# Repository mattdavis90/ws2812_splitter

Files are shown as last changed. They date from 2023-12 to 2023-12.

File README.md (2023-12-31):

# WS2812 Splitter

> [!WARNING]
> This project is still very much in beta and I am yet to receive the PCBs and fully verify the desgn.

A configurable splitter compatible with WS2812(B) LEDs. Splits the incoming signal two ways; the first is a copy of the input and the second is disabled for N LED's worth of data. This allows you to run two strips in parallel with each other.

The project is based on the work by [Pete on hackaday.io](https://hackaday.io/project/8181-ws2812b-delay-splitter). As far as I can tell Pete never got it working, this is intended to be a continuation of that work.

The project is being used personally for WS2812B Icicles. Rather than running wires from the bottom of each icicle back to the next LED (to create a continuous strip) this project allows you to place a 'tee' at the top of each icicle, that delays the continuing signal by the length of the drop.

This is maybe best viewed as an image

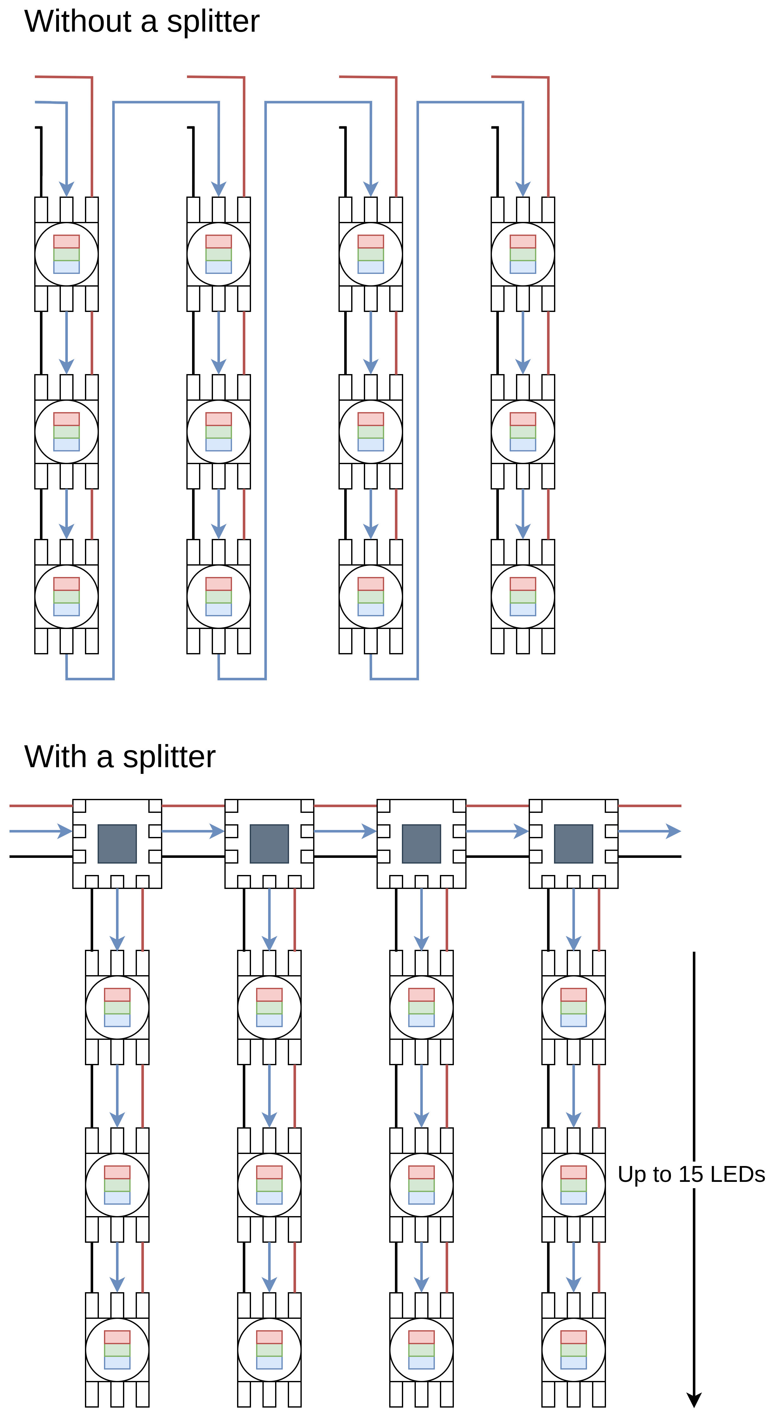
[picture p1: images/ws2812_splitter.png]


## Hardware

The design uses a Renesas SLG46826 SPLD to implement the logic required to detect the reset period, count LED words and generate the split signal.

A custom PCB was designed using the TSSOP-20 package to ease soldering. On board are 4 solder jumpers that set the length of the drop; between 0 and 15 LEDs.

### Renesas Greenpak Designer

The Renesas Greenpak software is free to download. I used the Ubuntu version successfully on Fedora. Mac and Windows are also available. This is a screenshot of the design I came up with. I went the multi-programmable chips; a little bit more expensive but I wanted to be sure the design worked and could be tweaked.

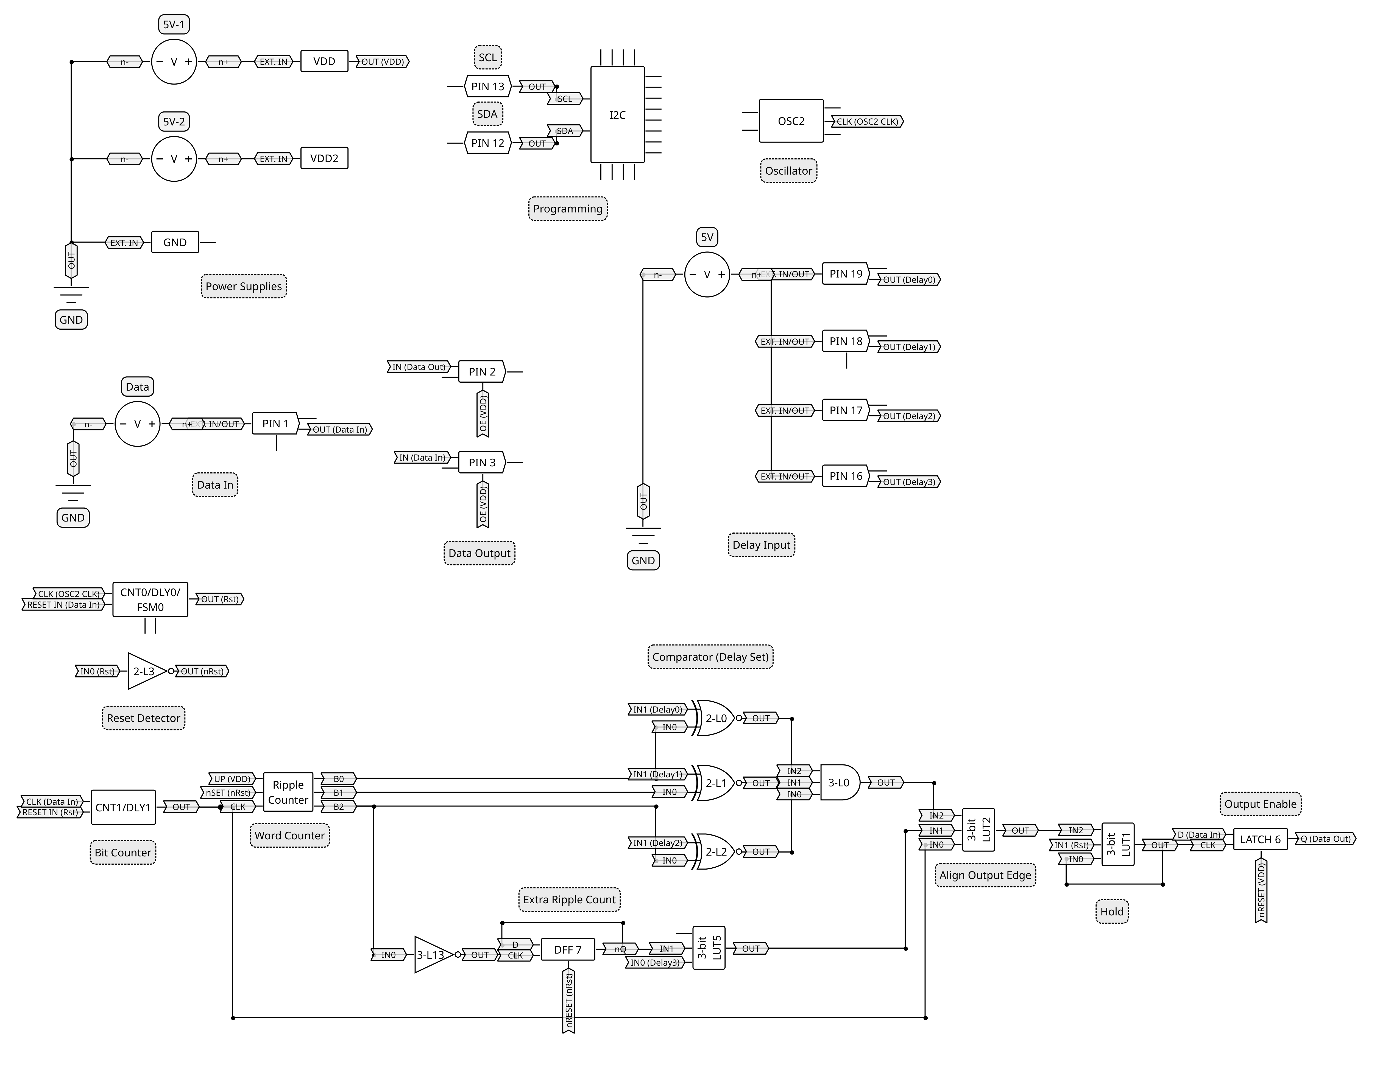
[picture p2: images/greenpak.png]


*Note*: Counters reset to `N` and trigger on 0 so should be set to `N-1`

Break down of macrocells

* Reset Detector
    - WS2812 datasheet states a minimum 50us reset period - data line held low
    - CNT0 is clocked by OSC2 at 25MHz, counting to 1249 (50us)
    - Generates `rst` and `nRst` nets
* Bit Counter
    - Clocked by incoming data on rising edges
    - Reset by the `rst` net
    - Counter set to 23 (24b - 1) generating a per-LED pulse
* Word Counter
    - Uses the built-in 3-bit ripple counter
    - Additionally a DFF is used to add a 4th bit to the counter
    - The counter is reset by `nRst`
* Delay Comparator
    - Compares the output of the ripple counter with the user input
    - The comparisons are ANDed together to generate an *output enable* signal
    - To fix the timing the Word Counter pulse is removed from the *output enable* signal
* Hold
    - The LUT acts as an SR-FlipFlop to hold the output latch High after the first comparison
    - The latch is reset by the `rst` net after >=50us of now input data

The design leaves several blocks unused which could be used to expand to >15 LEDs in future.

### PCB

The PCB is designed using KiCad 7 and manufactured by JLCPCB.

I aimed to keep in compact while still allowing hand soldering. The design uses the TSSOP package for the SLG and 0805 (2012) resistors and capacitors. The input signal is on `J2`, `J3` carries a regenerated signal down the icicle, `J4` carries the signal that is missing the first `N` LEDs worth of data; LEDs after this point will act as though they are at the end of the icicle.

`N` is set using `JP1-4` using binary - the pads can be soldered and desoldered easily.

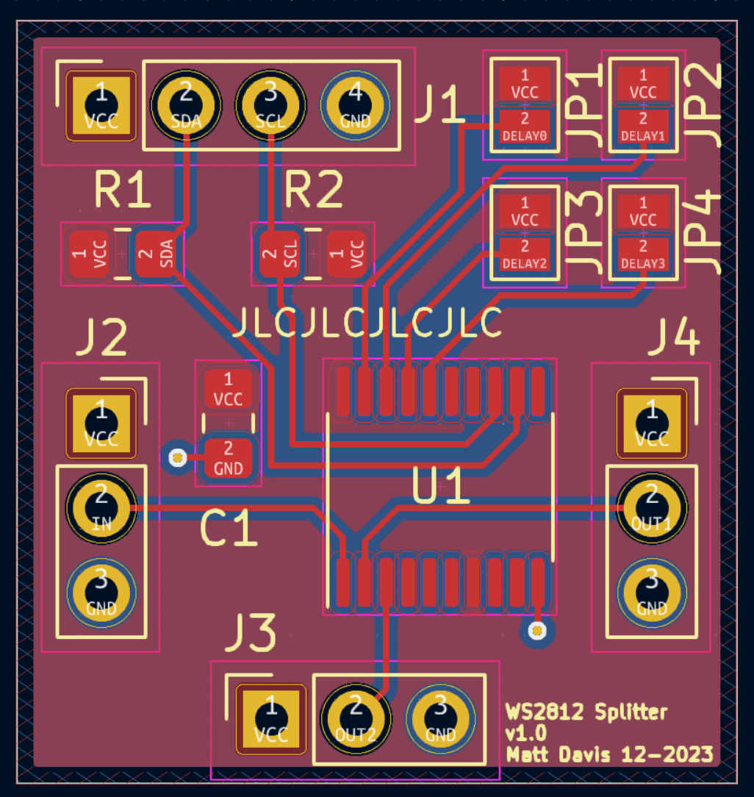
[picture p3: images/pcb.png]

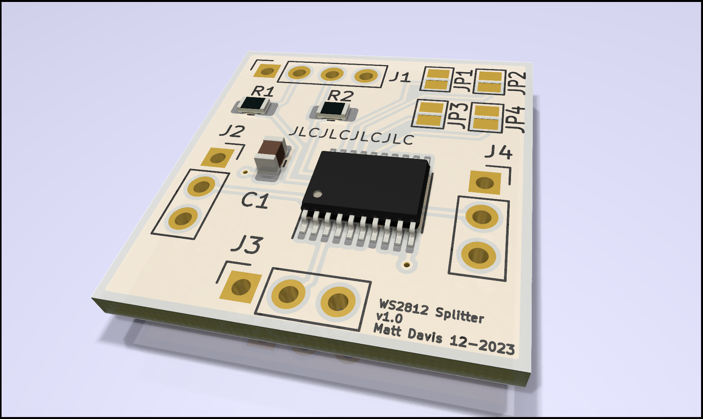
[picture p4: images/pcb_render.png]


## Programming

The `J1` header on the PCB is designed as a programming header. It provides power and I2C connectivity to the chip. To program the SLG46826 I used a pogo pin assembly from eBay and a CH341A chip. I'm using [this](https://github.com/Steve-Tech/i2c-ch341-usb) fork of the Linux CH341A I2C module because it supports kernel 6.4+

I wrote a custom SLG programmer to talk I2C over a standard Linux `/dev/i2c-#` device, available [here](https://github.com/mattdavis90/slg_programmer)

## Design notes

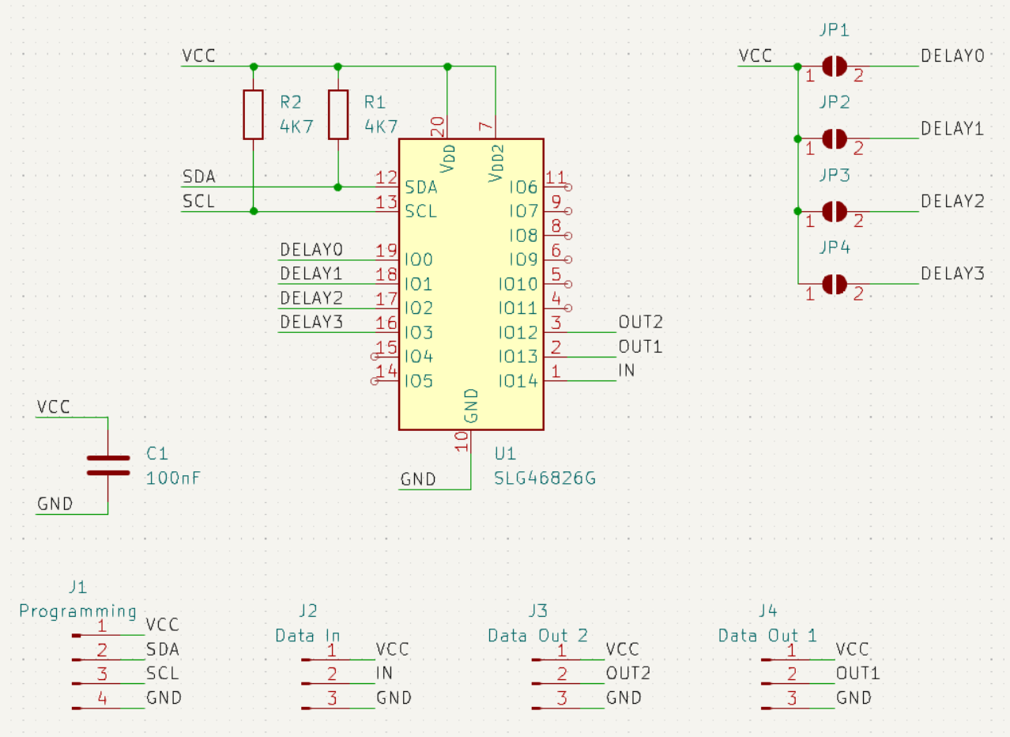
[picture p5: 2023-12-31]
images/schematic.png

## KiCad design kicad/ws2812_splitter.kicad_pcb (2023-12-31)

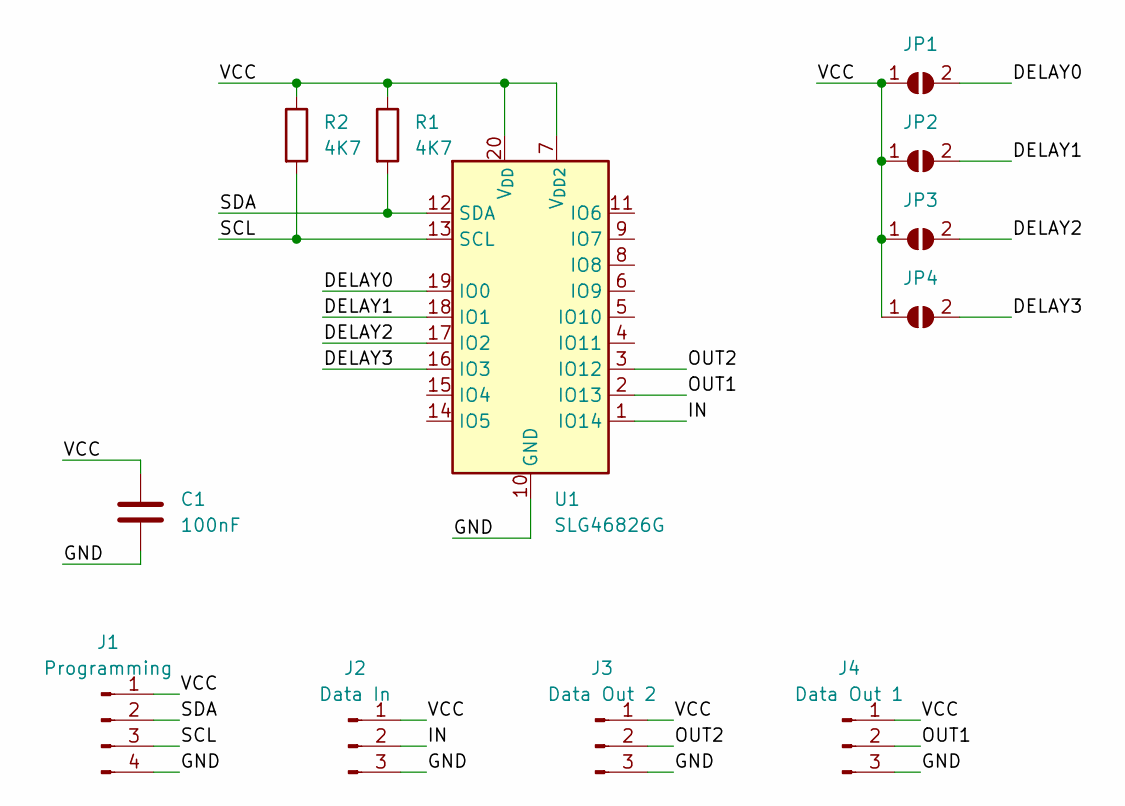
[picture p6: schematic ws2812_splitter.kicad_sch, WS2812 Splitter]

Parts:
C1: 100nF; C_0805_2012Metric_Pad1.18x1.45mm_HandSolder
J1: Programming; PinSocket_1x04_P2.54mm_Vertical
J2: Data In; PinSocket_1x03_P2.54mm_Vertical
J3: Data Out 2; PinSocket_1x03_P2.54mm_Vertical
J4: Data Out 1; PinSocket_1x03_P2.54mm_Vertical
JP1: Delay0; SolderJumper-2_P1.3mm_Open_Pad1.0x1.5mm
JP2: Delay1; SolderJumper-2_P1.3mm_Open_Pad1.0x1.5mm
JP3: Delay2; SolderJumper-2_P1.3mm_Open_Pad1.0x1.5mm
JP4: Delay3; SolderJumper-2_P1.3mm_Open_Pad1.0x1.5mm
R1, R2: 4K7; R_0805_2012Metric_Pad1.20x1.40mm_HandSolder
U1: SLG46826G; TSSOP-20_4.4x6.5mm_P0.65mm

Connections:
/DELAY0: JP1.2 (B), U1.19 (IO0)
/DELAY1: JP2.2 (B), U1.18 (IO1)
/DELAY2: JP3.2 (B), U1.17 (IO2)
/DELAY3: JP4.2 (B), U1.16 (IO3)
/GND: C1.2, J1.4, J2.3, J3.3, J4.3, U1.10 (GND)
/IN: J2.2, U1.1 (IO14)
/OUT1: J4.2, U1.2 (IO13)
/OUT2: J3.2, U1.3 (IO12)
/SCL: J1.3, R2.2, U1.13 (SCL)
/SDA: J1.2, R1.2, U1.12 (SDA)
/VCC: C1.1, J1.1, J2.1, J3.1, J4.1, JP1.1 (A), JP2.1 (A), JP3.1 (A), JP4.1 (A), R1.1, R2.1, U1.7 (V_{DD2}), U1.20 (V_{DD})

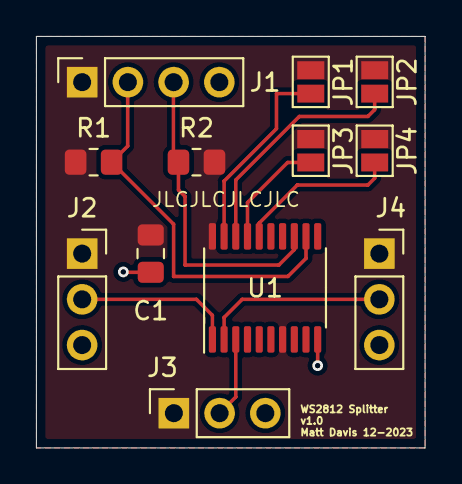
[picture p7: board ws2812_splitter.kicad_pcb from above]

Board: 2 copper layers, 21.6 x 22.9 mm, 12 parts (0 on the bottom side), 11 nets.
